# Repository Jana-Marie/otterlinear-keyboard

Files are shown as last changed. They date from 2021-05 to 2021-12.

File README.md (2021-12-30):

# otterlinear-keyboard

Just a smol ortholinear keyboard desgined by an otter for otters. It is built upon an STM32f042, Kailh Choc switches, featuring a Type-C jack and a wooden base. The keyboard measures only 214x84x17mm and has a smol, slim and chic design to fulfill its purpose as tv keyboard for my living room :3

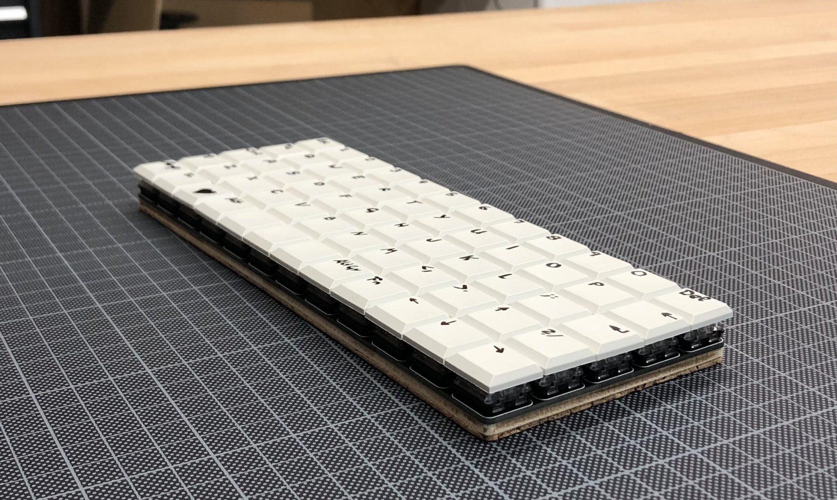
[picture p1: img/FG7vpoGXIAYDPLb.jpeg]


The board itself can be ordered from JLCPCB with all parts populated (if available..), keycaps can be acquired e.g. via AliExpress. The design was focused both on a clean and minimal appearance, and a clean board layout with just the necessary parts.

### Status
 - **HW:** 100%
 - **FW:** 60%

### To-do
 - Finish firmware
   - Write keyboard layout mapper
   - find an easy way to map a new layout

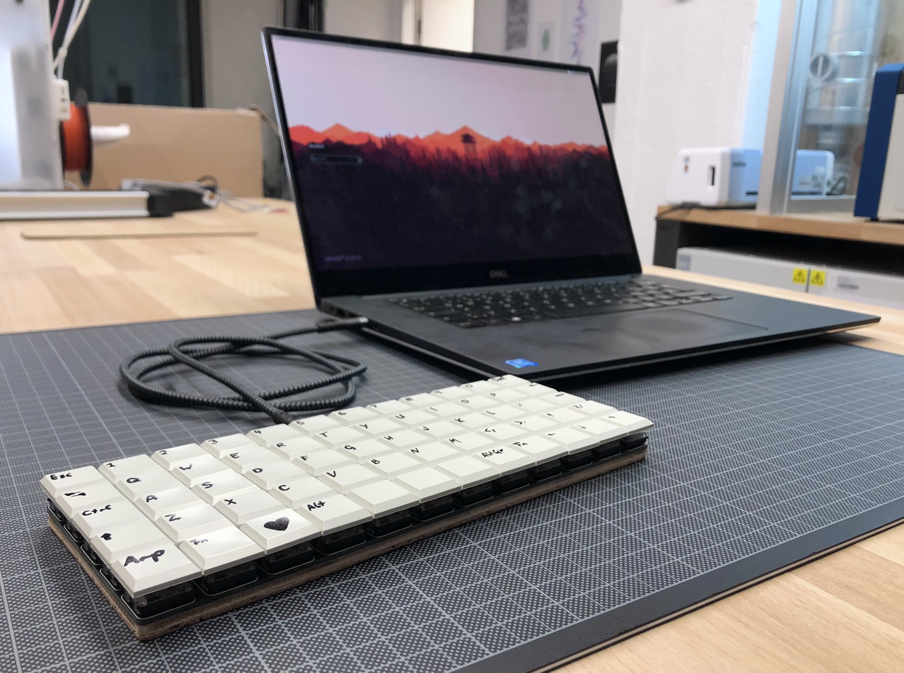
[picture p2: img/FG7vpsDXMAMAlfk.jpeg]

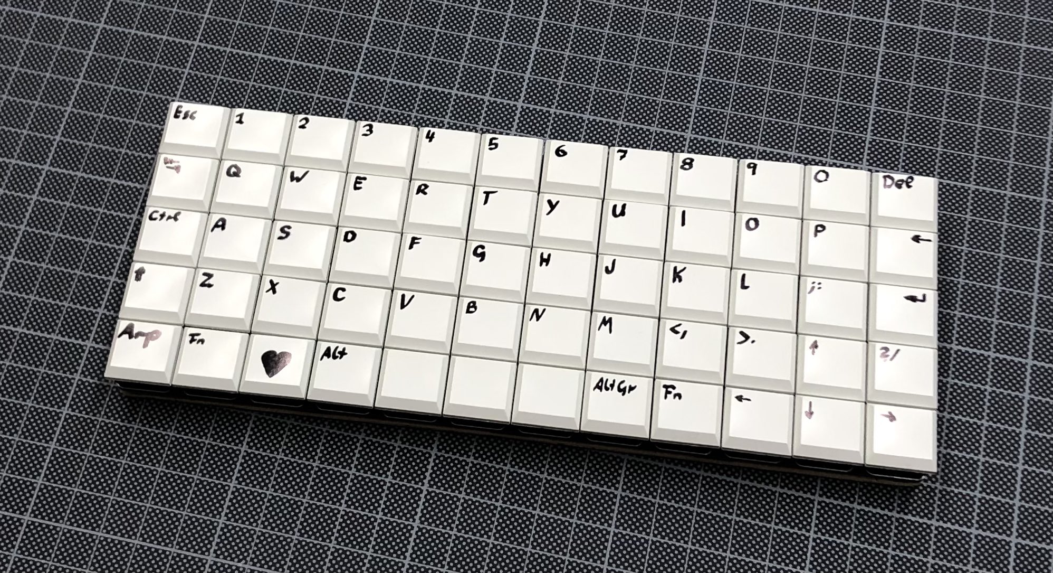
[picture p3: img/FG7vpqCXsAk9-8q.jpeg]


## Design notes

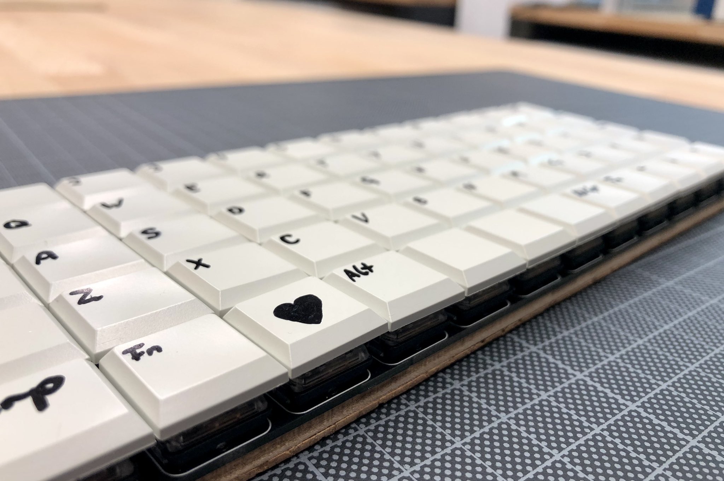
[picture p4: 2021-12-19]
img/FG7vppNX0AsBVcW.jpeg

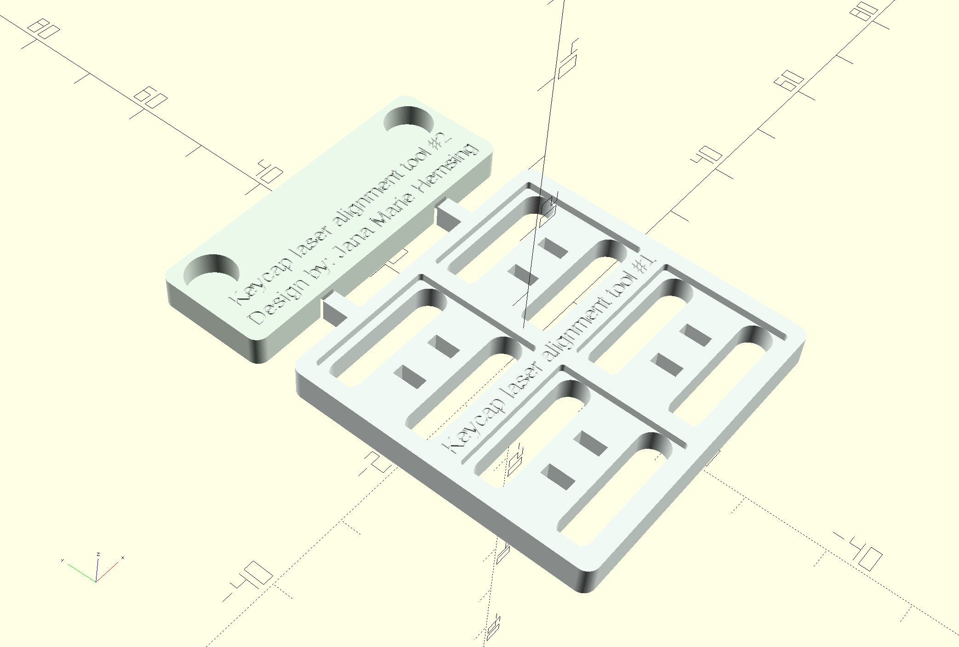
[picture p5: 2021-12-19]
tooling/gif/frame00027.png

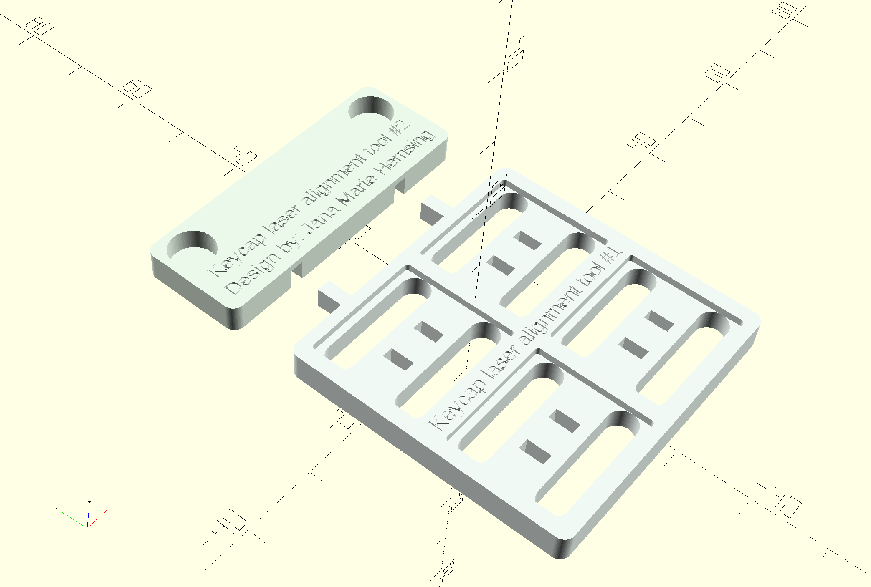
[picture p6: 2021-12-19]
tooling/gif/frame00059.png

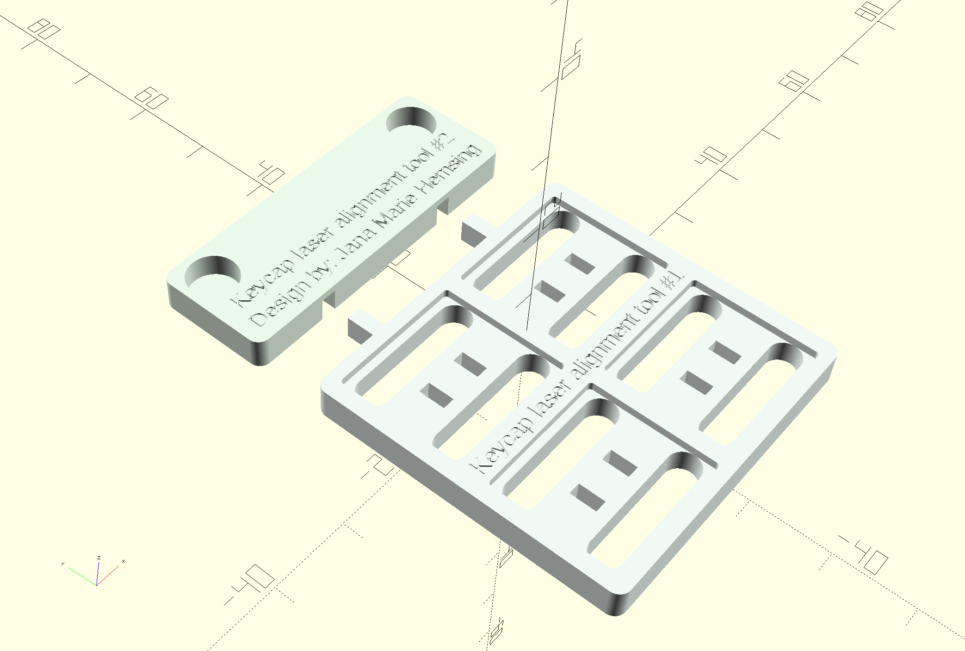
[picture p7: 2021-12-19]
tooling/gif/frame00052.png

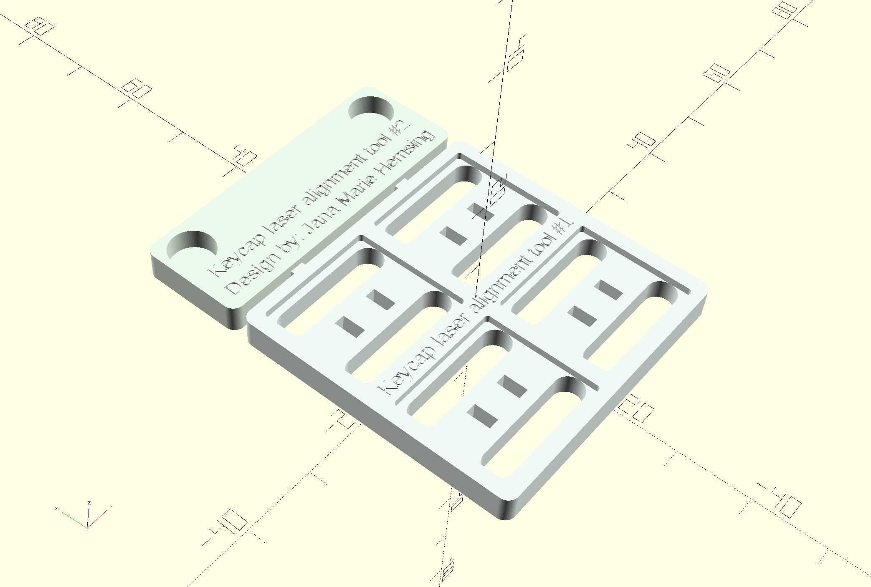
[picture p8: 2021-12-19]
tooling/gif/frame00006.png

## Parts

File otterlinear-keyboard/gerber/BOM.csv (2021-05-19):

Comment | Designator | Footprint | LCSC
100n | C1,C5,C6 | otter:C_0402 | C1525
1u | C2,C3,C4 | otter:C_0402 | C52923
1N4148WS | D56,D51,D46,D41,D36,D31,D26,D21,D16,D11,D6,D1,D57,D52,D47,D42,D37,D32,D27,D22,D17,D12,D7,D2,D58,D53,D48,D43,D38,D33,D28,D23,D18,D13,D8,D3,D59,D54,D49,D44,D39,D34,D29,D24,D19,D14,D9,D4,D60,D55,D50,D45,D40,D35,D30,D25,D20,D15,D10,D5 | Diode_SMD:D_SOD-323 | C2128
SP0502BAHT | D61 | Package_TO_SOT_SMD:SOT-23 | C32677
9774020360 | H2,H1,H3,H4 | otter:9774020360 | DNP
USB | J1 | otter:USB-C 16Pin | C393939
TC2030-CTX-Tag-Connect | P1 | otter:TC2030 | DNP
5k1 | R1,R2 | otter:R_0402 | C25905
PG1353 | SW56,SW51,SW46,SW41,SW36,SW31,SW26,SW21,SW16,SW11,SW6,SW1,SW57,SW52,SW47,SW42,SW37,SW32,SW27,SW22,SW17,SW12,SW7,SW2,SW58,SW53,SW48,SW43,SW38,SW33,SW28,SW23,SW18,SW13,SW8,SW3,SW59,SW54,SW49,SW44,SW39,SW34,SW29,SW24,SW19,SW14,SW9,SW4,SW60,SW55,SW50,SW45,SW40,SW35,SW30,SW25,SW20,SW15,SW10,SW5 | otter:PG1353 | DNP
STM32F042K6Ux | U1 | Package_DFN_QFN:QFN-32-1EP_5x5mm_P0.5mm_EP3.45x3.45mm | C110616
XC6206PxxxMR | U2 | Package_TO_SOT_SMD:SOT-23 | C5446

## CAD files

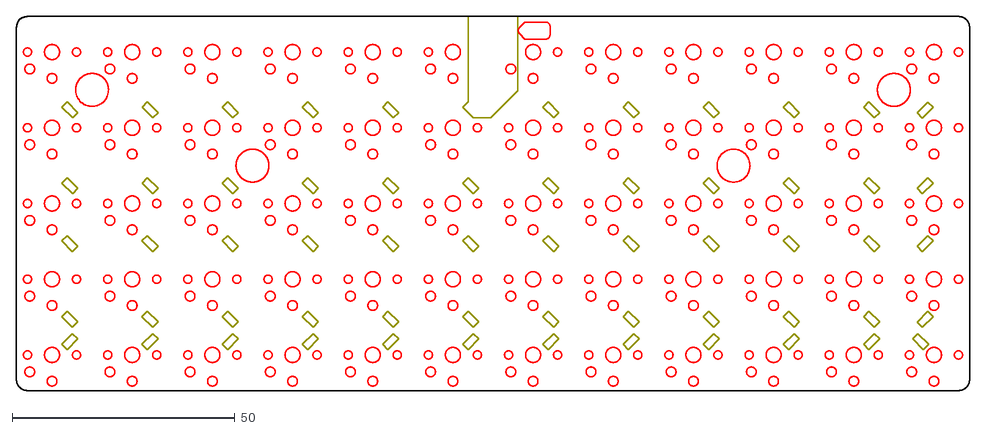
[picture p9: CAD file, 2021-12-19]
otterlinear-keyboard/laserfiles/ortholinear-keyboard-brd-Jana-Marie_1.dxf
214.0 x 84.0

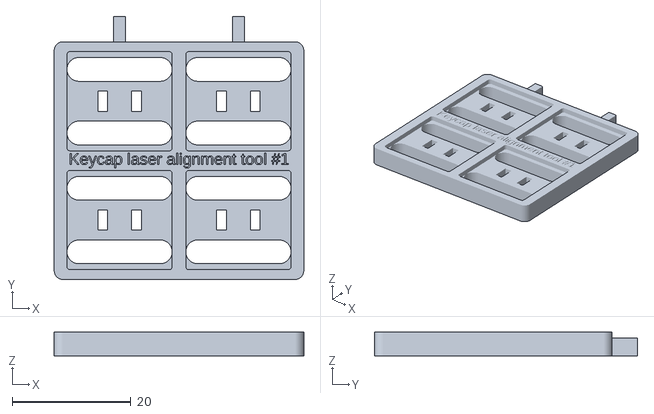
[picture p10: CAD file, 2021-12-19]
tooling/laser_keyholder_holder.stl
42.0 x 44.2 x 4.01

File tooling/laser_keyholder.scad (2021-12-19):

$fn = 100;
renderCap = false;
text1 = "Keycap laser alignment tool #1";
text2 = "Keycap laser alignment tool #2";
text3 = "Design by: Jana Marie Hemsing";
font = "Liberation Sans";
 
//%translate([0,50,0])color("DarkTurquoise")cylinder(d=2,h=10);
translate([0,-10*sin($t*100),0])holder();
//aligner();

if(renderCap == true){
    for(i = [-1:2:1]){
        for(j = [-1:2:1]){
            %translate([10*i,10*j,3]) keycap();
        }
    }
}

module aligner(){
    color("Honeydew")
    difference(){
        union(){
            translate([0,40/2+15/2+0.1,2])
            minkowski(){
                cylinder(h=0.01,d=3);
                cube([42-3,15-3,4],center=true);
            }
        }
        union(){
            for(i = [-1:2:1]){
                translate([10*i,17.5+5,1.5])cube([2.1,5.1,3.1],center=true);
                translate([(42/2-4)*i,31,1])cylinder(d=6.2,h=4);
            }
            translate([0,26,3.8]) linear_extrude(height = 0.5) {
                text(text = str(text2), font = font, size = 2, valign = "center", halign = "center");
            }
            translate([0,22.5,3.8]) linear_extrude(height = 0.5) {
                text(text = str(text3), font = font, size = 2, valign = "center", halign = "center");
            }
        }
    }
}

module holder(){
    color("MintCream")
    difference(){
        union(){
            translate([0,0,2])
            minkowski(){
                cylinder(h=0.01,d=3);
                cube([42-3,40-3,4],center=true);
            }
            for(i = [-1:2:1]){
                translate([10*i,17.5+4.5,1.5])cube([2,4.5,3],center=true);
            }
        }
        union(){
            for(i = [-1:2:1]){
                for(j = [-1:2:1]){
                    translate([10*i,10*j,3]) keycap(0.2);
                    translate([10*i,10*j,-1]) pillars(0.2);
                }
            }
            translate([0,0,3.8]) linear_extrude(height = 0.5) {
                text(text = str(text1), font = font, size = 2, valign = "center", halign = "center");
            }
        }
    }
}

module pillars(,expand = 0,dia1 = 4){
    for(j = [-1:2:1]){
        hull(){
            for(i = [-1:2:1]){
                translate([((17.5-dia1+expand)/2)*i,((14.5-dia1+expand)/2)*j,0]) cylinder(d=dia1,h=5);
            }
        }
    }
}


// keycap
// todo legs
module keycap(expand = 0){
    color("DeepPink")
    difference(){
        union(){
            dia1 = 1;
            minkowski(){
                cylinder(h=3,d1=dia1,d2=1);
                cube([17.5-dia1+expand,16.5-dia1+expand,0.1],center=true);
            }
            for(i = [-1:2:1]){
                translate([(5.7/2)*i,0,-2]) cube([1.6,3.4,4],center=true);
            }
        }
        union(){
        }
    }
}

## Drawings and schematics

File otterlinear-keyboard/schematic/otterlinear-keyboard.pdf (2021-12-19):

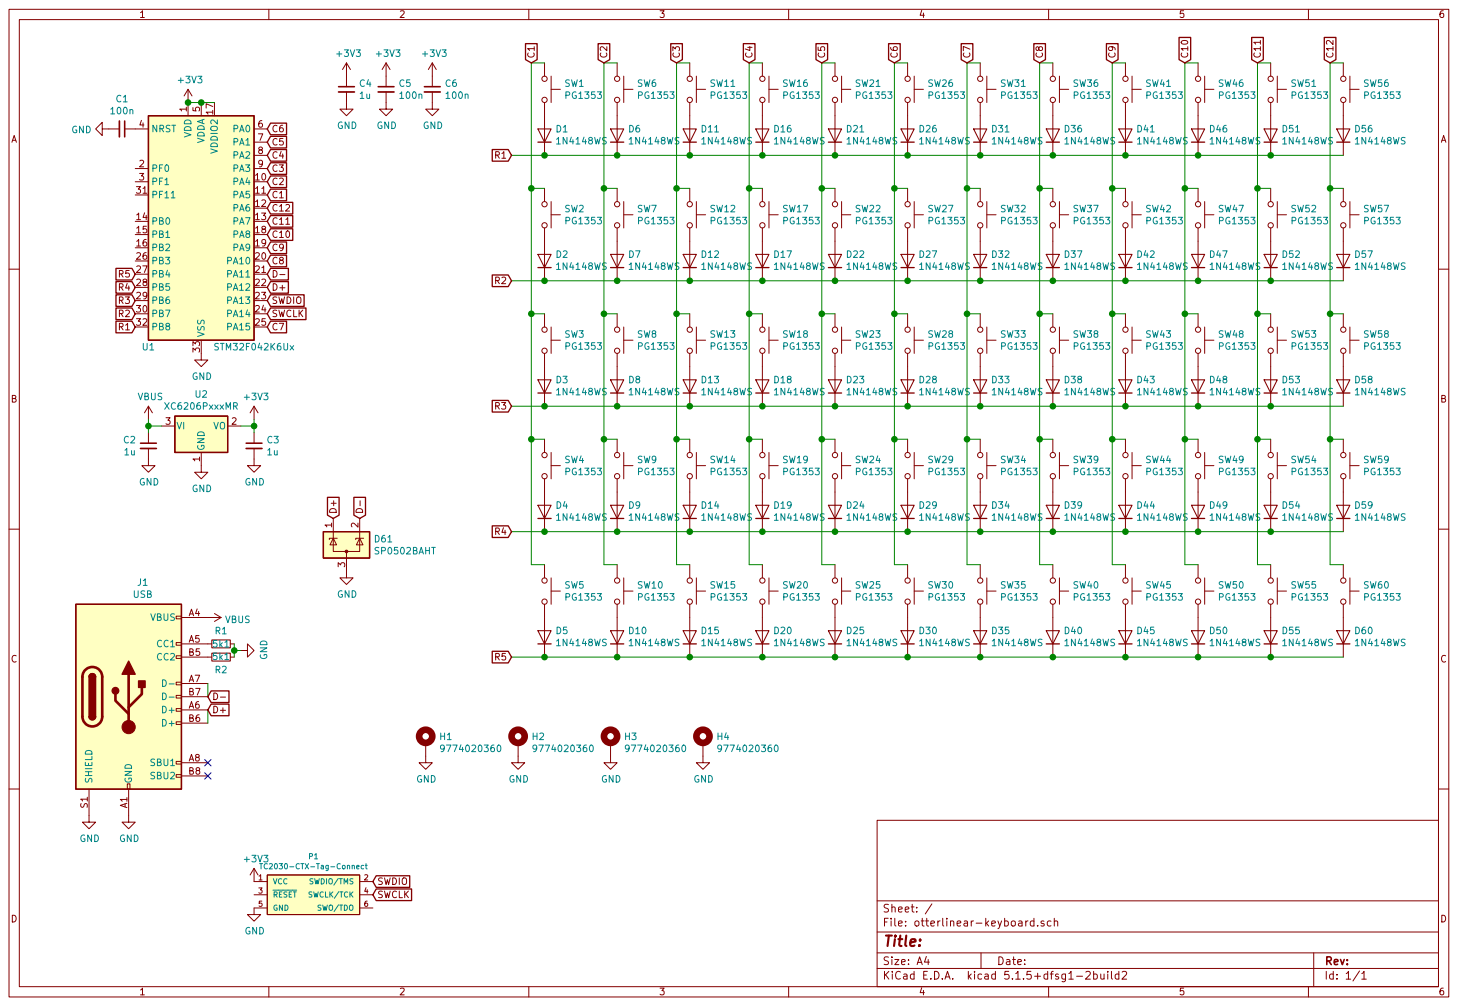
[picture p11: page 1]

File: otterlinear-keyboard.sch Sheet: / D14

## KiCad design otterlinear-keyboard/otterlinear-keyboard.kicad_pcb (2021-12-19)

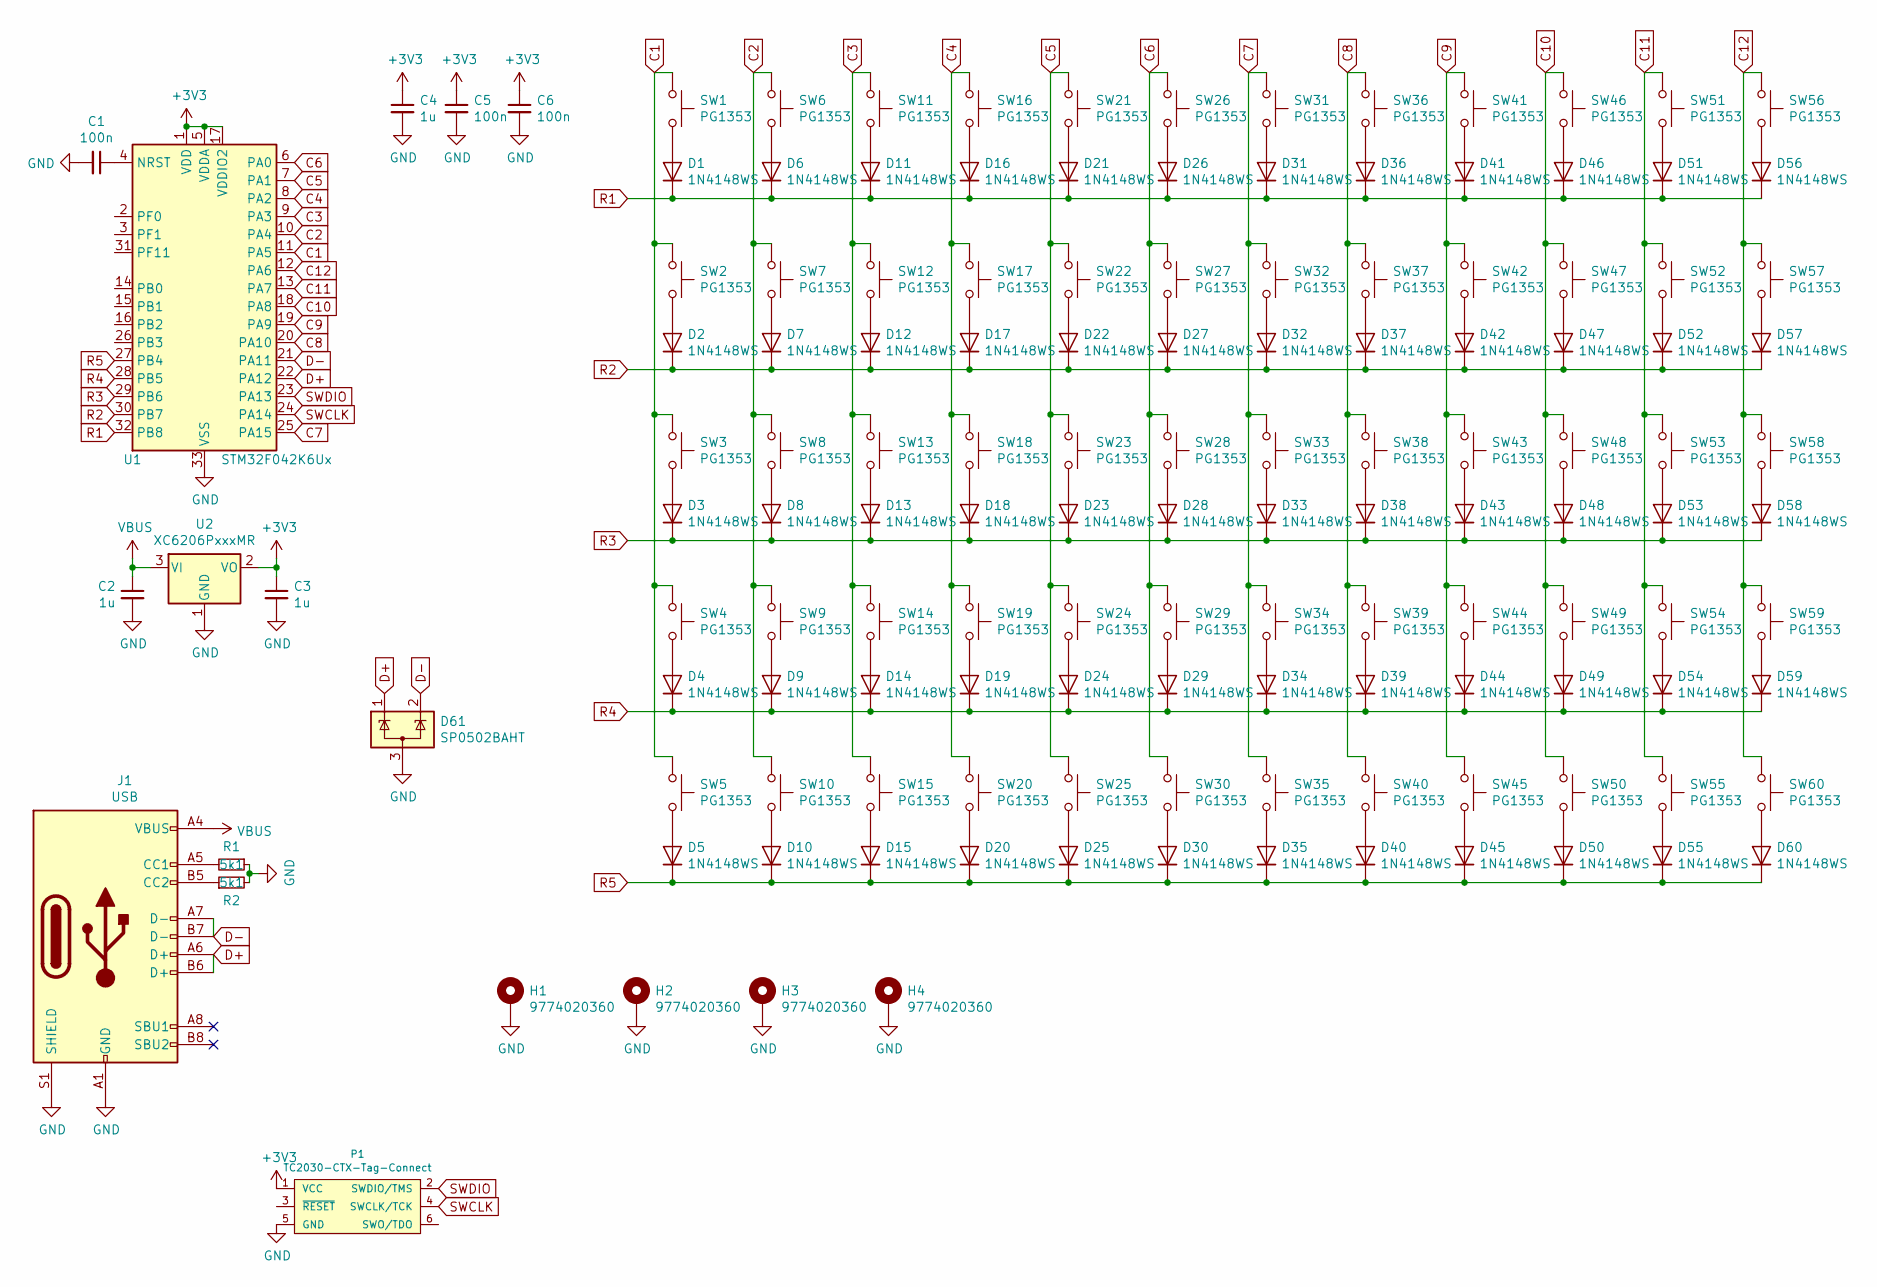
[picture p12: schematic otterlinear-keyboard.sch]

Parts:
C1, C5, C6: 100n; C_0402
C2, C3, C4: 1u; C_0402
D1, D2, D3, D4, D5, D6, D7, D8, D9, D10, D11, D12, D13, D14, D15, D16, D17, D18, D19, D20, D21, D22, D23, D24, D25, D26, D27, D28, D29, D30, D31, D32, D33, D34, D35, D36, D37, D38, D39, D40, D41, D42, D43, D44, D45, D46, D47, D48, D49, D50, D51, D52, D53, D54, D55, D56, D57, D58, D59, D60: 1N4148WS; D_SOD-323
D61: SP0502BAHT; SOT-23
H1, H2, H3, H4: 9774020360
J1: USB; USB-C 16Pin
P1: TC2030-CTX-Tag-Connect; TC2030
R1, R2: 5k1; R_0402
SW1, SW2, SW3, SW4, SW5, SW6, SW7, SW8, SW9, SW10, SW11, SW12, SW13, SW14, SW15, SW16, SW17, SW18, SW19, SW20, SW21, SW22, SW23, SW24, SW25, SW26, SW27, SW28, SW29, SW30, SW31, SW32, SW33, SW34, SW35, SW36, SW37, SW38, SW39, SW40, SW41, SW42, SW43, SW44, SW45, SW46, SW47, SW48, SW49, SW50, SW51, SW52, SW53, SW54, SW55, SW56, SW57, SW58, SW59, SW60: PG1353
U1: STM32F042K6Ux; QFN-32-1EP_5x5mm_P0.5mm_EP3.45x3.45mm
U2: XC6206PxxxMR; SOT-23

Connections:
+3V3: C3.1, C4.1, C5.1, C6.1, P1.1 (VCC), U1.1 (VDD), U1.5 (VDDA), U1.17 (VDDIO2), U2.2 (VO)
C1: SW1.1, SW2.1, SW3.1, SW4.1, SW5.1, U1.11 (PA5)
C2: SW6.1, SW7.1, SW8.1, SW9.1, SW10.1, U1.10 (PA4)
C3: SW11.1, SW12.1, SW13.1, SW14.1, SW15.1, U1.9 (PA3)
C4: SW16.1, SW17.1, SW18.1, SW19.1, SW20.1, U1.8 (PA2)
C5: SW21.1, SW22.1, SW23.1, SW24.1, SW25.1, U1.7 (PA1)
C6: SW26.1, SW27.1, SW28.1, SW29.1, SW30.1, U1.6 (PA0)
C7: SW31.1, SW32.1, SW33.1, SW34.1, SW35.1, U1.25 (PA15)
C8: SW36.1, SW37.1, SW38.1, SW39.1, SW40.1, U1.20 (PA10)
C9: SW41.1, SW42.1, SW43.1, SW44.1, SW45.1, U1.19 (PA9)
C10: SW46.1, SW47.1, SW48.1, SW49.1, SW50.1, U1.18 (PA8)
C11: SW51.1, SW52.1, SW53.1, SW54.1, SW55.1, U1.13 (PA7)
C12: SW56.1, SW57.1, SW58.1, SW59.1, SW60.1, U1.12 (PA6)
D+: D61.1 (K), J1.A6 (D+), J1.B6 (D+), U1.22 (PA12)
D-: D61.2 (K), J1.A7 (D-), J1.B7 (D-), U1.21 (PA11)
GND: C1.2, C2.2, C3.2, C4.2, C5.2, C6.2, D61.3 (A), H1.1, H2.1, H3.1, H4.1, J1.A1 (GND), J1.A12 (GND), J1.B1 (GND), J1.B12 (GND), J1.S1 (SHIELD), P1.5 (GND), R1.1, R2.2, U1.33 (VSS), U2.1 (GND)
unnamed: C1.1, U1.4 (NRST)
unnamed: D1.2 (A), SW1.2
unnamed: D2.2 (A), SW2.2
unnamed: D3.2 (A), SW3.2
unnamed: D4.2 (A), SW4.2
unnamed: D5.2 (A), SW5.2
unnamed: D6.2 (A), SW6.2
unnamed: D7.2 (A), SW7.2
unnamed: D8.2 (A), SW8.2
unnamed: D9.2 (A), SW9.2
unnamed: D10.2 (A), SW10.2
unnamed: D11.2 (A), SW11.2
unnamed: D12.2 (A), SW12.2
unnamed: D13.2 (A), SW13.2
unnamed: D14.2 (A), SW14.2
unnamed: D15.2 (A), SW15.2
unnamed: D16.2 (A), SW16.2
unnamed: D17.2 (A), SW17.2
unnamed: D18.2 (A), SW18.2
unnamed: D19.2 (A), SW19.2
unnamed: D20.2 (A), SW20.2
unnamed: D21.2 (A), SW21.2
unnamed: D22.2 (A), SW22.2
unnamed: D23.2 (A), SW23.2
unnamed: D24.2 (A), SW24.2
unnamed: D25.2 (A), SW25.2
unnamed: D26.2 (A), SW26.2
unnamed: D27.2 (A), SW27.2
unnamed: D28.2 (A), SW28.2
unnamed: D29.2 (A), SW29.2
unnamed: D30.2 (A), SW30.2
unnamed: D31.2 (A), SW31.2
unnamed: D32.2 (A), SW32.2
unnamed: D33.2 (A), SW33.2
unnamed: D34.2 (A), SW34.2
unnamed: D35.2 (A), SW35.2
unnamed: D36.2 (A), SW36.2
unnamed: D37.2 (A), SW37.2
unnamed: D38.2 (A), SW38.2
unnamed: D39.2 (A), SW39.2
unnamed: D40.2 (A), SW40.2
unnamed: D41.2 (A), SW41.2
unnamed: D42.2 (A), SW42.2
unnamed: D43.2 (A), SW43.2
unnamed: D44.2 (A), SW44.2
unnamed: D45.2 (A), SW45.2
unnamed: D46.2 (A), SW46.2
unnamed: D47.2 (A), SW47.2
unnamed: D48.2 (A), SW48.2
unnamed: D49.2 (A), SW49.2
unnamed: D50.2 (A), SW50.2
unnamed: D51.2 (A), SW51.2
unnamed: D52.2 (A), SW52.2
unnamed: D53.2 (A), SW53.2
unnamed: D54.2 (A), SW54.2
unnamed: D55.2 (A), SW55.2
unnamed: D56.2 (A), SW56.2
unnamed: D57.2 (A), SW57.2
unnamed: D58.2 (A), SW58.2
unnamed: D59.2 (A), SW59.2
unnamed: D60.2 (A), SW60.2
unnamed: J1.A5 (CC1), R1.2
unnamed: J1.B5 (CC2), R2.1
R1: D1.1 (K), D6.1 (K), D11.1 (K), D16.1 (K), D21.1 (K), D26.1 (K), D31.1 (K), D36.1 (K), D41.1 (K), D46.1 (K), D51.1 (K), D56.1 (K), U1.32 (PB8)
R2: D2.1 (K), D7.1 (K), D12.1 (K), D17.1 (K), D22.1 (K), D27.1 (K), D32.1 (K), D37.1 (K), D42.1 (K), D47.1 (K), D52.1 (K), D57.1 (K), U1.30 (PB7)
R3: D3.1 (K), D8.1 (K), D13.1 (K), D18.1 (K), D23.1 (K), D28.1 (K), D33.1 (K), D38.1 (K), D43.1 (K), D48.1 (K), D53.1 (K), D58.1 (K), U1.29 (PB6)
R4: D4.1 (K), D9.1 (K), D14.1 (K), D19.1 (K), D24.1 (K), D29.1 (K), D34.1 (K), D39.1 (K), D44.1 (K), D49.1 (K), D54.1 (K), D59.1 (K), U1.28 (PB5)
R5: D5.1 (K), D10.1 (K), D15.1 (K), D20.1 (K), D25.1 (K), D30.1 (K), D35.1 (K), D40.1 (K), D45.1 (K), D50.1 (K), D55.1 (K), D60.1 (K), U1.27 (PB4)
SWCLK: P1.4 (SWCLK/TCK), U1.24 (PA14)
SWDIO: P1.2 (SWDIO/TMS), U1.23 (PA13)
VBUS: C2.1, J1.A4 (VBUS), J1.A9 (VBUS), J1.B4 (VBUS), J1.B9 (VBUS), U2.3 (VI)

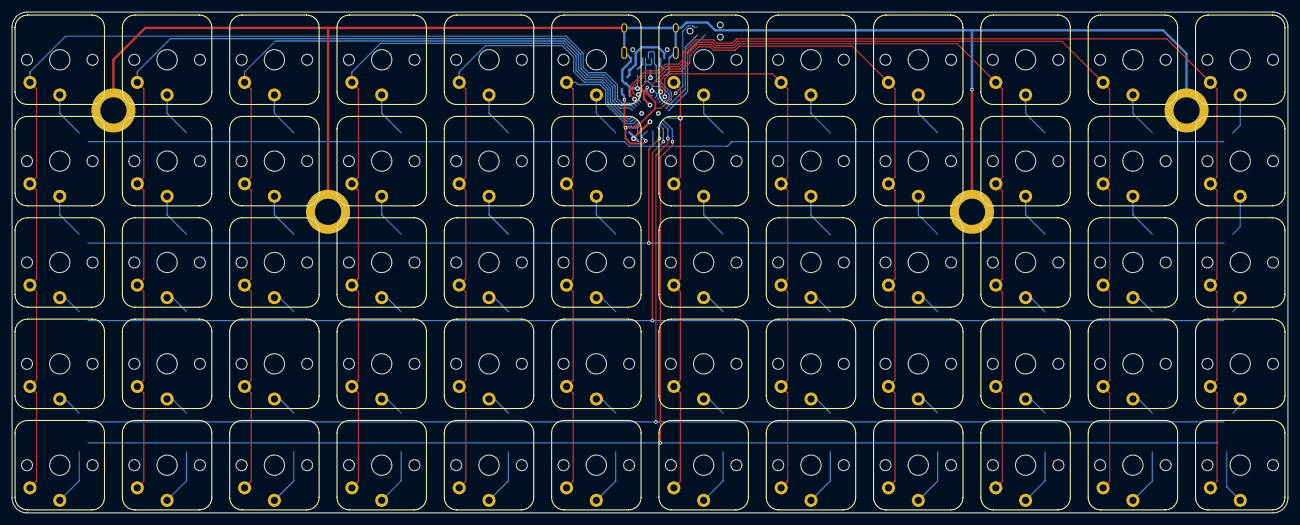
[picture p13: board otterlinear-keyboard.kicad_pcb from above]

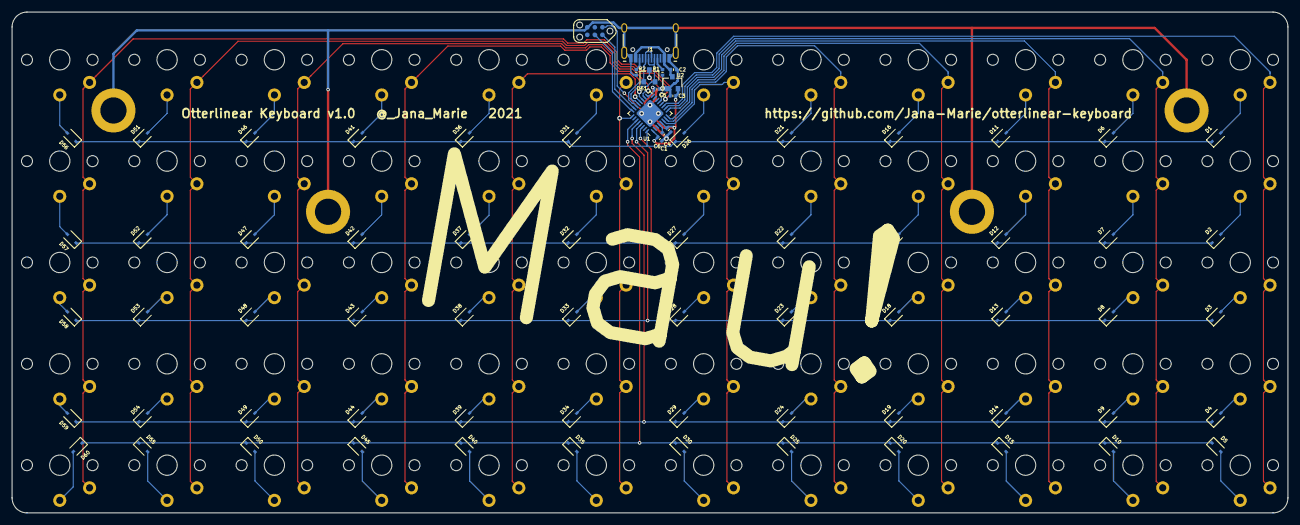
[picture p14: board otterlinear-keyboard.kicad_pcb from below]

Board: 2 copper layers, 214.0 x 84.0 mm, 137 parts (77 on the bottom side), 87 nets.

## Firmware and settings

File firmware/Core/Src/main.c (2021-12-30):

#include "main.h"
#include "usb_device.h"
#include "usbd_hid.h"
#include "mapping.h"

TIM_HandleTypeDef htim1;
DMA_HandleTypeDef hdma_tim1_ch1;
DMA_HandleTypeDef hdma_tim1_ch3_up;
PCD_HandleTypeDef hpcd_USB_FS;

void SystemClock_Config(void);
static void MX_GPIO_Init(void);
static void MX_DMA_Init(void);
static void MX_TIM1_Init(void);
void check_bootloader(void);
void run_bootloader(void);
void append_key(uint8_t key);
void clear_key_list();

struct key_t{
    uint8_t id;
    uint8_t modifier;
    uint8_t reserved;
    uint8_t keycode[6];
} key;

struct keylist_t{
  uint8_t keycode[6];
  uint8_t numkeys;
  key_t usb_key
  //void (*append)(uint8_t key);
  //void (*clear)();
} keylist;// = {.append = append_key, .clear = clear_key_list};

uint16_t drive_map[12] = {
  0b0000000000100000,
  0b0000000000010000,
  0b0000000000001000,
  0b0000000000000100,
  0b0000000000000010,
  0b0000000000000001,
  0b1000000000000000,
  0b0000010000000000,
  0b0000001000000000,
  0b0000000100000000,
  0b0000000010000000,
  0b0000000001000000
};

uint16_t receive_map[12] = {};
uint16_t key_map[5] = {};

int main(void)
{
  HAL_Init();
  run_bootloader();
  SystemClock_Config();
  MX_GPIO_Init();
  //MX_DMA_Init();
  //MX_TIM1_Init();
  check_bootloader();
  MX_USB_HID_INIT();

  while (1)
  {
    for(uint8_t i = 0; i < 12; i++){
      GPIOA->ODR = drive_map[i];
      HAL_Delay(1);
      receive_map[i] = GPIOB->IDR >> 4;
      for(int k = 0; k < 5; k++){ // map rotated by 90deg
        key_map[k] = (key_map[k] & ~(1ul << i)) | (((receive_map[i] >> k) & 0x01) << i);
      }
      HAL_Delay(2);
    }

    key.id = 1;
    key.modifier = 0;

    if(key_map[2] == 1) key.modifier |= 0x01;
    if(key_map[1] == 1) key.modifier |= 0x02;
    if(key_map[0] == 1) key.modifier |= 0x01;
    if(key_map[0] >> 3 == 1) key.modifier |= 0x04;
    if(key_map[0] >> 7 == 1) key.modifier |= 0x04;

    uint8_t keycode_cnt = 0;
    for(uint8_t i = 0; i <= 4; i++){
      for(uint8_t k = 0; k <= 12; k++){
        if(((key_map[i] >> k) & 0x01) == 1){
          if(layer_0[i][k] != 0x00) {
            key.keycode[keycode_cnt++] = layer_0[i][k];
          }
        }
      }
    }

    USBD_HID_SendReport(&hUsbDeviceFS, (uint8_t *)&key, sizeof(key));
    keycode_cnt = 0;
    memset(&key, 0, sizeof key);
  }
}

// ####### Keyhandling #######
//
void append_key(uint8_t key){
  keylist.keycode[keylist.numkeys] = key;
};

void clear_key_list(){

};

// ####### Bootloader #######

void run_bootloader(void){
  if ( *((unsigned long *)0x200017FC) == 0xDEADBEEF ) {
    void (*SysMemBootJump)(void);
    volatile uint32_t addr = 0x1FFFC400;

    HAL_RCC_DeInit();
    SysTick->CTRL = 0;
    SysTick->LOAD = 0;
    SysTick->VAL = 0;

    FLASH_EraseInitTypeDef EraseInitStruct;
    uint32_t SECTORError = 0;;
    HAL_FLASH_Unlock();
    EraseInitStruct.TypeErase = FLASH_TYPEERASE_PAGES;
    EraseInitStruct.PageAddress = 0x08000000; // start address
    EraseInitStruct.NbPages = 1;

    if (HAL_FLASHEx_Erase(&EraseInitStruct, &SECTORError) != HAL_OK)
    {
    	SECTORError = SECTORError + 1;
    }

    SYSCFG->CFGR1 = 0x01;
    SysMemBootJump = (void (*)(void)) (*((uint32_t *)(addr + 4)));
    __set_MSP(*(uint32_t *)addr);

    SysMemBootJump();

    while (1);
  }
}

void check_bootloader(void){
  for(uint8_t i = 0; i < 12; i++){
    GPIOA->ODR = drive_map[i];
    HAL_Delay(1);
    receive_map[i] = GPIOB->IDR >> 4;
    HAL_Delay(1);
  }
  if(receive_map[4] == 3 && receive_map[5] == 3 && receive_map[6] == 3){
    *((unsigned long *)0x200017FC) = 0xDEADBEEF;
    NVIC_SystemReset();
  }
}

// ####### Init #######

void SystemClock_Config(void)
{
  RCC_OscInitTypeDef RCC_OscInitStruct = {0};
  RCC_ClkInitTypeDef RCC_ClkInitStruct = {0};
  RCC_PeriphCLKInitTypeDef PeriphClkInit = {0};

  RCC_OscInitStruct.OscillatorType = RCC_OSCILLATORTYPE_HSI48;
  RCC_OscInitStruct.HSI48State = RCC_HSI48_ON;
  RCC_OscInitStruct.PLL.PLLState = RCC_PLL_NONE;
  HAL_RCC_OscConfig(&RCC_OscInitStruct);

  RCC_ClkInitStruct.ClockType = RCC_CLOCKTYPE_HCLK|RCC_CLOCKTYPE_SYSCLK
                              |RCC_CLOCKTYPE_PCLK1;
  RCC_ClkInitStruct.SYSCLKSource = RCC_SYSCLKSOURCE_HSI48;
  RCC_ClkInitStruct.AHBCLKDivider = RCC_SYSCLK_DIV1;
  RCC_ClkInitStruct.APB1CLKDivider = RCC_HCLK_DIV1;
  HAL_RCC_ClockConfig(&RCC_ClkInitStruct, FLASH_LATENCY_1);

  PeriphClkInit.PeriphClockSelection = RCC_PERIPHCLK_USB;
  PeriphClkInit.UsbClockSelection = RCC_USBCLKSOURCE_HSI48;
  HAL_RCCEx_PeriphCLKConfig(&PeriphClkInit);
}

static void MX_TIM1_Init(void)
{
  TIM_ClockConfigTypeDef sClockSourceConfig = {0};
  TIM_MasterConfigTypeDef sMasterConfig = {0};
  TIM_OC_InitTypeDef sConfigOC = {0};
  TIM_BreakDeadTimeConfigTypeDef sBreakDeadTimeConfig = {0};

  htim1.Instance = TIM1;
  htim1.Init.Prescaler = 0;
  htim1.Init.CounterMode = TIM_COUNTERMODE_UP;
  htim1.Init.Period = 65535;
  htim1.Init.ClockDivision = TIM_CLOCKDIVISION_DIV1;
  htim1.Init.RepetitionCounter = 0;
  htim1.Init.AutoReloadPreload = TIM_AUTORELOAD_PRELOAD_DISABLE;
  HAL_TIM_Base_Init(&htim1);

  sClockSourceConfig.ClockSource = TIM_CLOCKSOURCE_INTERNAL;
  HAL_TIM_ConfigClockSource(&htim1, &sClockSourceConfig);
  HAL_TIM_OC_Init(&htim1);

  sMasterConfig.MasterOutputTrigger = TIM_TRGO_RESET;
  sMasterConfig.MasterSlaveMode = TIM_MASTERSLAVEMODE_DISABLE;
  HAL_TIMEx_MasterConfigSynchronization(&htim1, &sMasterConfig);

  sConfigOC.OCMode = TIM_OCMODE_TIMING;
  sConfigOC.Pulse = 0;
  sConfigOC.OCPolarity = TIM_OCPOLARITY_HIGH;
  sConfigOC.OCNPolarity = TIM_OCNPOLARITY_HIGH;
  sConfigOC.OCFastMode = TIM_OCFAST_DISABLE;
  sConfigOC.OCIdleState = TIM_OCIDLESTATE_RESET;
  sConfigOC.OCNIdleState = TIM_OCNIDLESTATE_RESET;
  HAL_TIM_OC_ConfigChannel(&htim1, &sConfigOC, TIM_CHANNEL_1);
  HAL_TIM_OC_ConfigChannel(&htim1, &sConfigOC, TIM_CHANNEL_3);

  sBreakDeadTimeConfig.OffStateRunMode = TIM_OSSR_DISABLE;
  sBreakDeadTimeConfig.OffStateIDLEMode = TIM_OSSI_DISABLE;
  sBreakDeadTimeConfig.LockLevel = TIM_LOCKLEVEL_OFF;
  sBreakDeadTimeConfig.DeadTime = 0;
  sBreakDeadTimeConfig.BreakState = TIM_BREAK_DISABLE;
  sBreakDeadTimeConfig.BreakPolarity = TIM_BREAKPOLARITY_HIGH;
  sBreakDeadTimeConfig.AutomaticOutput = TIM_AUTOMATICOUTPUT_DISABLE;
  HAL_TIMEx_ConfigBreakDeadTime(&htim1, &sBreakDeadTimeConfig);
}


static void MX_DMA_Init(void)
{

  __HAL_RCC_DMA1_CLK_ENABLE();

  HAL_NVIC_SetPriority(DMA1_Channel2_3_IRQn, 0, 0);
  HAL_NVIC_EnableIRQ(DMA1_Channel2_3_IRQn);
  HAL_NVIC_SetPriority(DMA1_Channel4_5_IRQn, 0, 0);
  HAL_NVIC_EnableIRQ(DMA1_Channel4_5_IRQn);
}

static void MX_GPIO_Init(void)
{
  GPIO_InitTypeDef GPIO_InitStruct = {0};

  __HAL_RCC_GPIOA_CLK_ENABLE();
  __HAL_RCC_GPIOB_CLK_ENABLE();

  HAL_GPIO_WritePin(GPIOB, C6_Pin|C5_Pin|C4_Pin|C3_Pin
                          |C2_Pin|C1_Pin|C12_Pin|C11_Pin
                          |C10_Pin|C9_Pin|C8_Pin|C7_Pin, GPIO_PIN_RESET);

  GPIO_InitStruct.Pin = C6_Pin|C5_Pin|C4_Pin|C3_Pin
                          |C2_Pin|C1_Pin|C12_Pin|C11_Pin
                          |C10_Pin|C9_Pin|C8_Pin|C7_Pin;
  GPIO_InitStruct.Mode = GPIO_MODE_OUTPUT_PP;
  GPIO_InitStruct.Pull = GPIO_NOPULL;
  GPIO_InitStruct.Speed = GPIO_SPEED_FREQ_LOW;
  HAL_GPIO_Init(GPIOA, &GPIO_InitStruct);

  GPIO_InitStruct.Pin = R5_Pin|R4_Pin|R3_Pin|R2_Pin
                          |R1_Pin;
  GPIO_InitStruct.Mode = GPIO_MODE_INPUT;
  GPIO_InitStruct.Pull = GPIO_PULLDOWN;
  HAL_GPIO_Init(GPIOB, &GPIO_InitStruct);

}

void Error_Handler(void){
  while(1){

  }
}

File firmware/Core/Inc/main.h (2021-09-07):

#ifndef __MAIN_H
#define __MAIN_H

#include "stm32f0xx_hal.h"

void Error_Handler(void);

#define C6_Pin GPIO_PIN_0
#define C6_GPIO_Port GPIOA
#define C5_Pin GPIO_PIN_1
#define C5_GPIO_Port GPIOA
#define C4_Pin GPIO_PIN_2
#define C4_GPIO_Port GPIOA
#define C3_Pin GPIO_PIN_3
#define C3_GPIO_Port GPIOA
#define C2_Pin GPIO_PIN_4
#define C2_GPIO_Port GPIOA
#define C1_Pin GPIO_PIN_5
#define C1_GPIO_Port GPIOA
#define C12_Pin GPIO_PIN_6
#define C12_GPIO_Port GPIOA
#define C11_Pin GPIO_PIN_7
#define C11_GPIO_Port GPIOA
#define C10_Pin GPIO_PIN_8
#define C10_GPIO_Port GPIOA
#define C9_Pin GPIO_PIN_9
#define C9_GPIO_Port GPIOA
#define C8_Pin GPIO_PIN_10
#define C8_GPIO_Port GPIOA
#define C7_Pin GPIO_PIN_15
#define C7_GPIO_Port GPIOA
#define R5_Pin GPIO_PIN_4
#define R5_GPIO_Port GPIOB
#define R4_Pin GPIO_PIN_5
#define R4_GPIO_Port GPIOB
#define R3_Pin GPIO_PIN_6
#define R3_GPIO_Port GPIOB
#define R2_Pin GPIO_PIN_7
#define R2_GPIO_Port GPIOB
#define R1_Pin GPIO_PIN_8
#define R1_GPIO_Port GPIOB

#endif

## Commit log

2021-05-18 initial design
    [ortholinear-keyboard.kicad_pcb, ortholinear-keyboard.sch]
2021-05-19 added layou
    [ortholinear-keyboard.kicad_pcb]
2021-05-19 exported production files
    [ortholinear-keyboard-B_Cu.gbl, ortholinear-keyboard-B_Mask.gbs, ortholinear-keyboard-B_Paste.gbp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]
2021-05-19 updated production files
    [BOM.csv, ortholinear-keyboard.csv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]
2021-06-10 updated board files
    [ortholinear-keyboard-brd.dxf, ortholinear-keyboard.kicad_pcb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]
2021-09-08 renamed folder
    [BOM.csv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]
2021-09-08 added aligner design
    [laser_keyholder.scad]
2021-12-19 finished v1.0, renamed project, regenerated gerber
    [ortholinear-keyboard-B_Cu.gbl, ortholinear-keyboard-B_Mask.gbs, ortholinear-keyboard-B_Paste.gbp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]
2021-12-19 removed old files
    [ortholinear-keyboard.kicad_pcb, ortholinear-keyboard.sch]
2021-12-19 moved folder
    [BOM.csv, ortholinear-keyboard-brd-Jana-Marie_1.dxf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]
2021-12-19 updated tooling
    [laser_keyholder.scad, laser_keyholder_holder.stl]
